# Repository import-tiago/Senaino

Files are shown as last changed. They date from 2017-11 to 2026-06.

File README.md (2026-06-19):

# Senaino




Senaino is an educational microcontroller board inspired by the Arduino UNO and adapted for technical training at SENAI. It was designed to help students practice soldering, electronics, bootloader recording and embedded programming with components that are easy to source in Brazil.

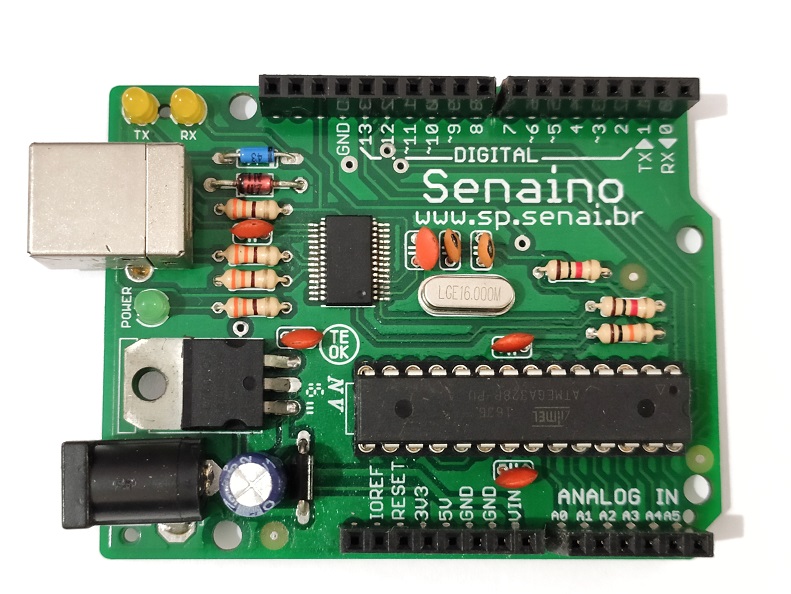
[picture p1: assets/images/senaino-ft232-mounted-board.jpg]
Senaino FT232 assembled board


## Overview

The goal was not only to make an Arduino-compatible board, but to create a reproducible hardware kit that could be fabricated, assembled and tested by students in a classroom or lab environment.

The work included schematic design, PCB layout, component selection, production files, assembly references, documentation and validation of the mounted board.

## Highlights

- Arduino UNO-inspired board based on the ATmega328P-PU.
- Two documented USB-to-serial variants: FT232RL and CH340G.
- Through-hole component strategy for beginner-friendly soldering practice.
- 16 MHz ATmega328P clock and Arduino-style headers.
- Open hardware files for Eagle, Gerber fabrication, schematic export and BOM.
- Dedicated assembly, testing, driver and bootloader documentation.

## Repository Map

```text
assets/
  images/          Project photos and workshop/gallery images.
  reference/       Board overlays and visual references for assembly.

docs/
  ft232/           FT232 assembly, BOM, production and testing notes.
  ch340/           CH340 assembly, BOM, production and testing notes.
  citation.md
  design-decisions.md
  drivers.md
  licensing.md
  variants.md

hardware/
  bom/             Spreadsheet and CSV bill of materials.
  eagle/           Eagle schematic and board files by variant.
  exports/         Schematic image/PDF exports.
  gerbers/         Fabrication files by variant.
```

## Documentation

- [Bootloader notes](docs/bootloader.md)
- [Citation and DOI guide](docs/citation.md)
- [Design decisions](docs/design-decisions.md)
- [Driver notes](docs/drivers.md)
- [License notes](docs/licensing.md)
- [Board variants](docs/variants.md)

| Variant | Assembly | Board overlay | BOM | Production | Testing |
|---|---|---|---|---|---|
| FT232 | [Guide](docs/ft232/assembly-guide.md) | [Overlay](assets/reference/senaino-ft232-components-silkscreen.png) | [BOM](docs/ft232/bill-of-materials.md) | [Files](docs/ft232/production.md) | [Checklist](docs/ft232/testing.md) |
| CH340 | [Guide](docs/ch340/assembly-guide.md) | [Overlay](assets/reference/senaino-ch340-components-silkscreen.png) | [BOM](docs/ch340/bill-of-materials.md) | [Files](docs/ch340/production.md) | [Checklist](docs/ch340/testing.md) |

## Hardware Files

| Variant | Eagle files | Schematic PDF | Gerbers | BOM |
|---|---|---|---|---|
| FT232 | [hardware/eagle/ft232-v1.0](hardware/eagle/ft232-v1.0) | [PDF](hardware/exports/senaino-ft232-schematic.pdf) | [Gerbers](hardware/gerbers/ft232-v1.0) | [CSV](hardware/bom/senaino-ft232-bom.csv) |
| CH340 | [hardware/eagle/ch340-v1.0](hardware/eagle/ch340-v1.0) | [PDF](hardware/exports/senaino-ch340-schematic.pdf) | [Gerbers](hardware/gerbers/ch340-v1.0) | [CSV](hardware/bom/senaino-ch340-bom.csv) |

## Board Variants

The repository documents two board variants in the `main` branch.

| Variant | USB-serial IC | Main advantage | Recommended use |
|---|---|---|---|
| FT232 | FT232RL | Traditional and widely documented | Original classroom version |
| CH340 | CH340G | Lower cost and avoids FT232 sourcing risk | Cost-sensitive or supply-risk-aware production |

The CH340 alternative exists because FT232RL sourcing can be risky. ZeptoBars documented real and fake FT232RL dies and described counterfeit/compatible chips that could behave differently with FTDI drivers: [FTDI FT232RL: real vs fake](https://zeptobars.com/en/read/FTDI-FT232RL-real-vs-fake-supereal).

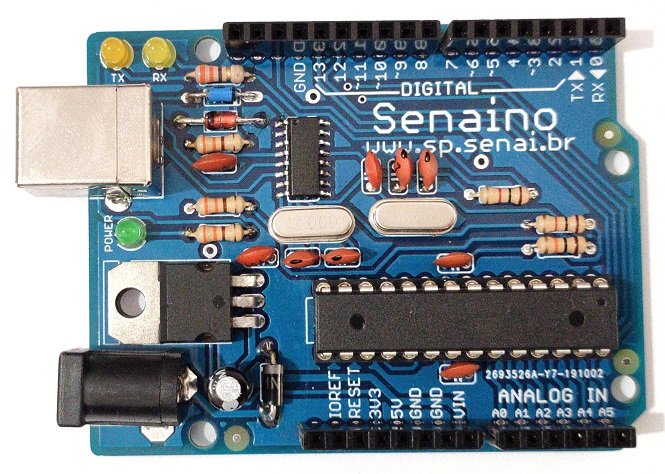
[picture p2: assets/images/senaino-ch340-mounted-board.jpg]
Senaino CH340 assembled board


## Gallery

| | | |
|---|---|---|
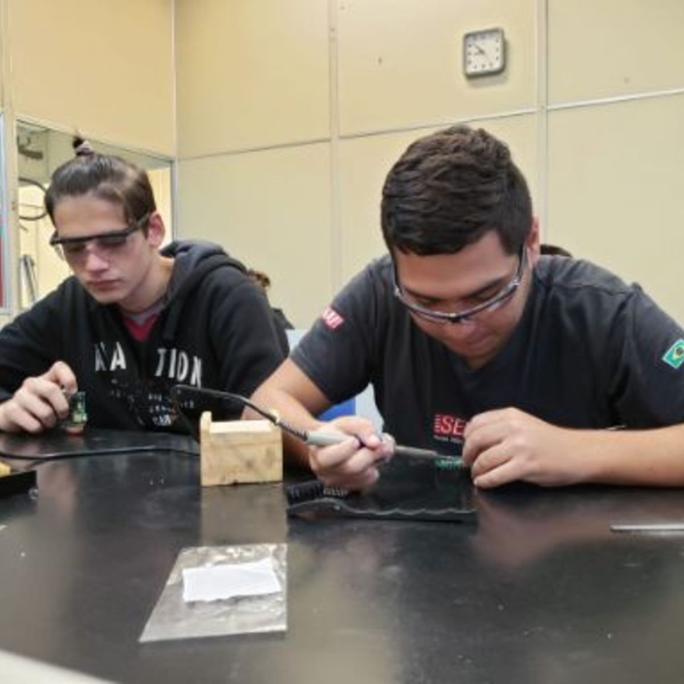
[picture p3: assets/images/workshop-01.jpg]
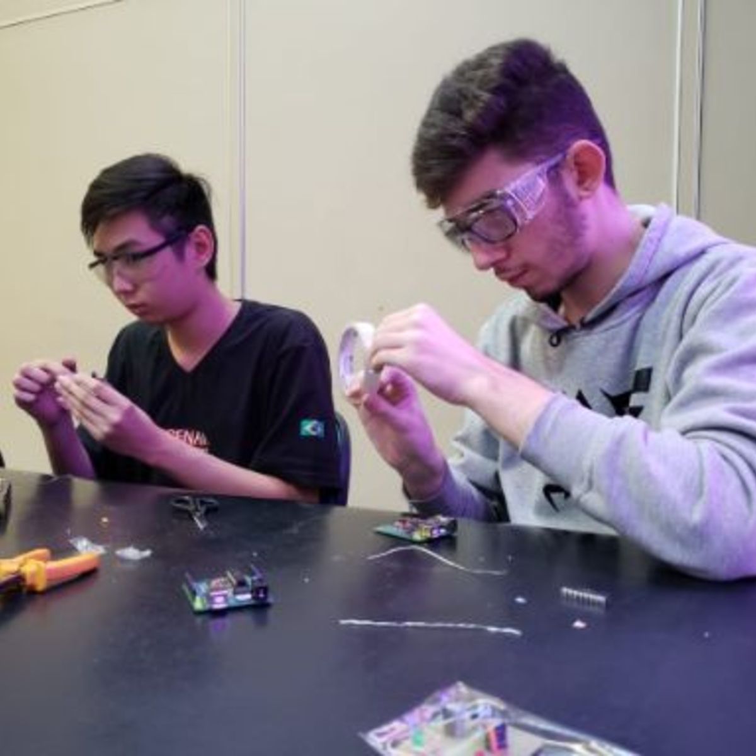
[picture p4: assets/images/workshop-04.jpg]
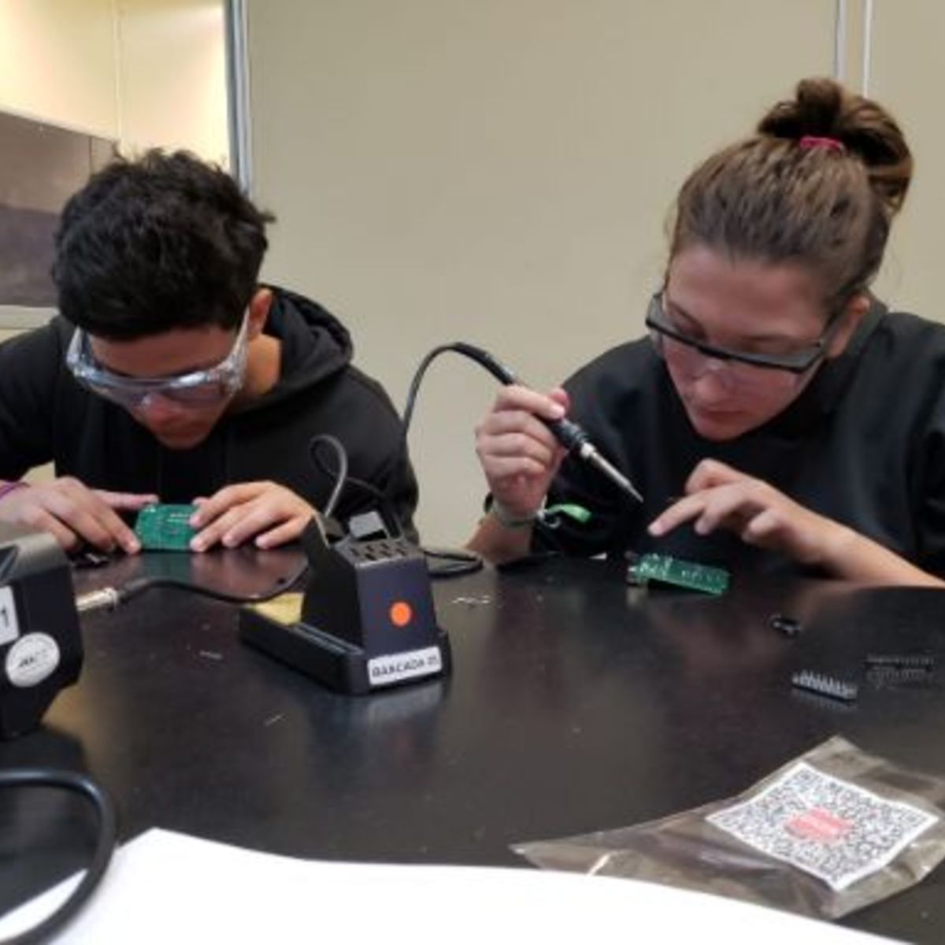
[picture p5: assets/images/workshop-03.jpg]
|  |  |  |
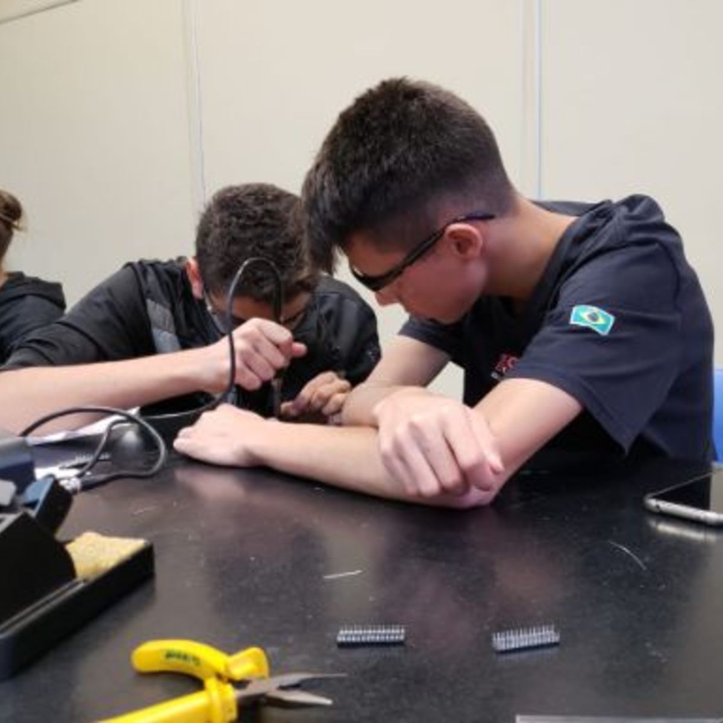
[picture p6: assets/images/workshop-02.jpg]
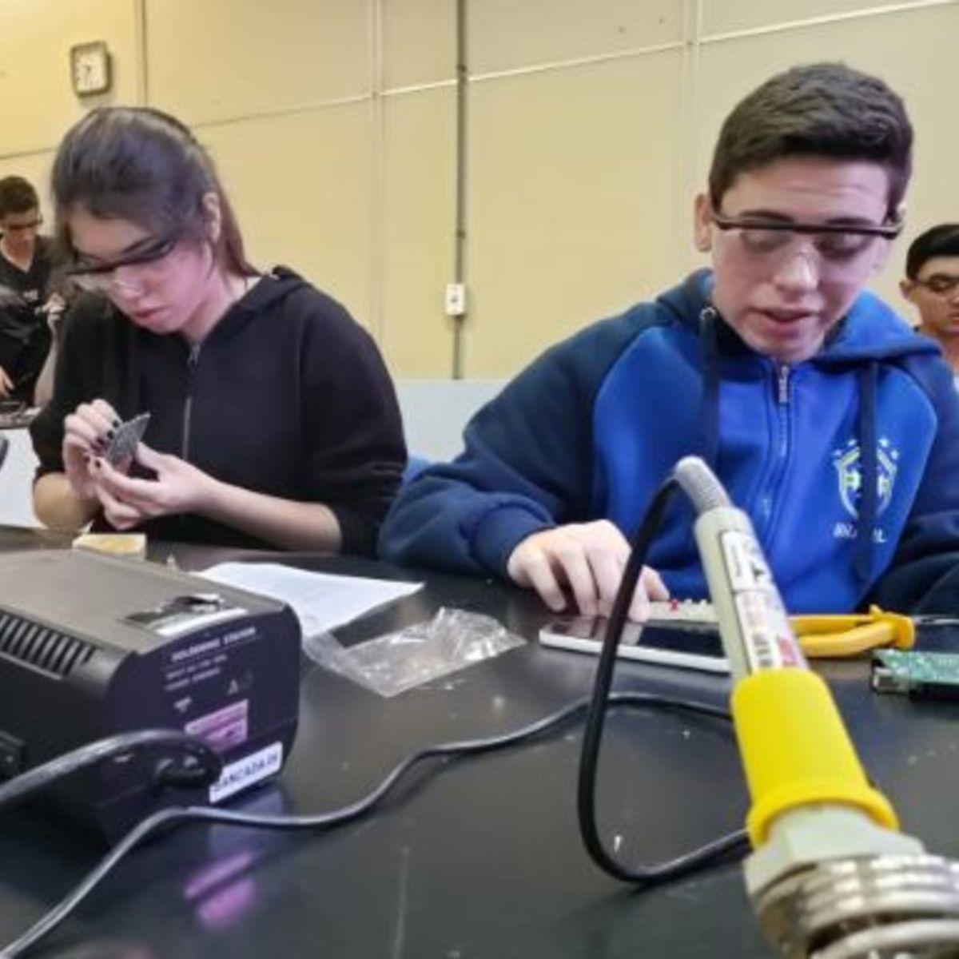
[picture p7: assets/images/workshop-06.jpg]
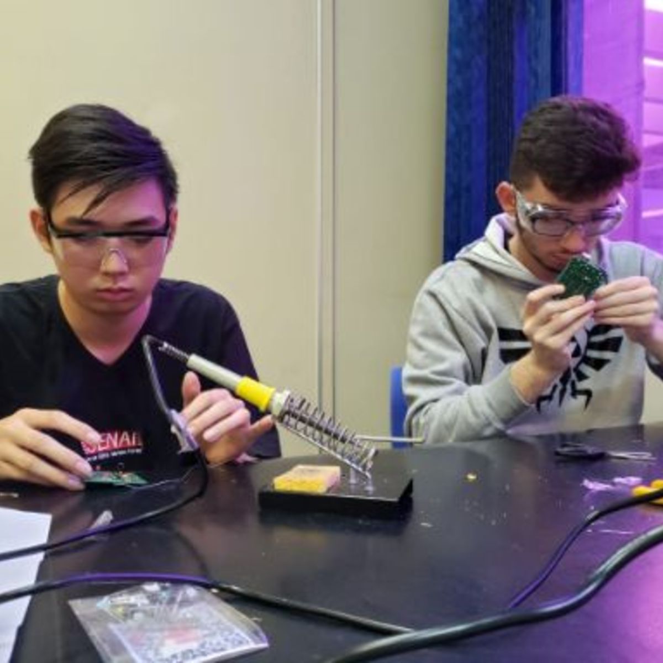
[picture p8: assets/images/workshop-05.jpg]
|  |  |  |
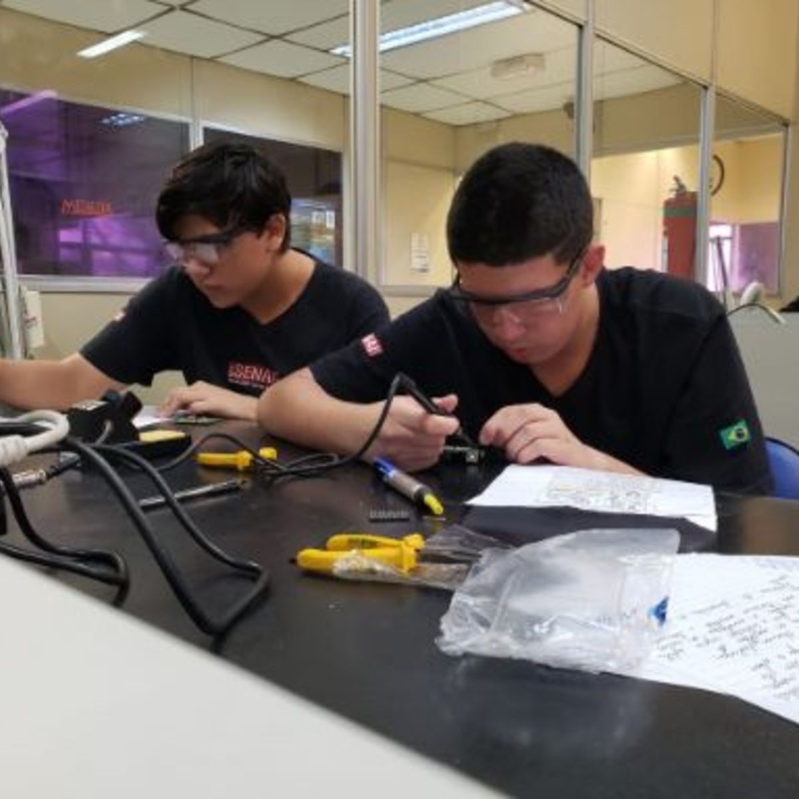
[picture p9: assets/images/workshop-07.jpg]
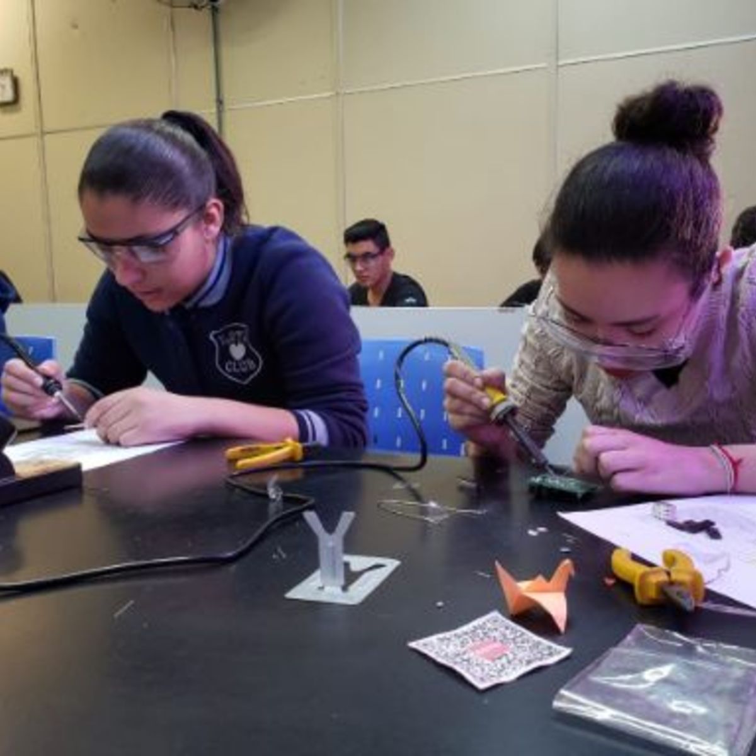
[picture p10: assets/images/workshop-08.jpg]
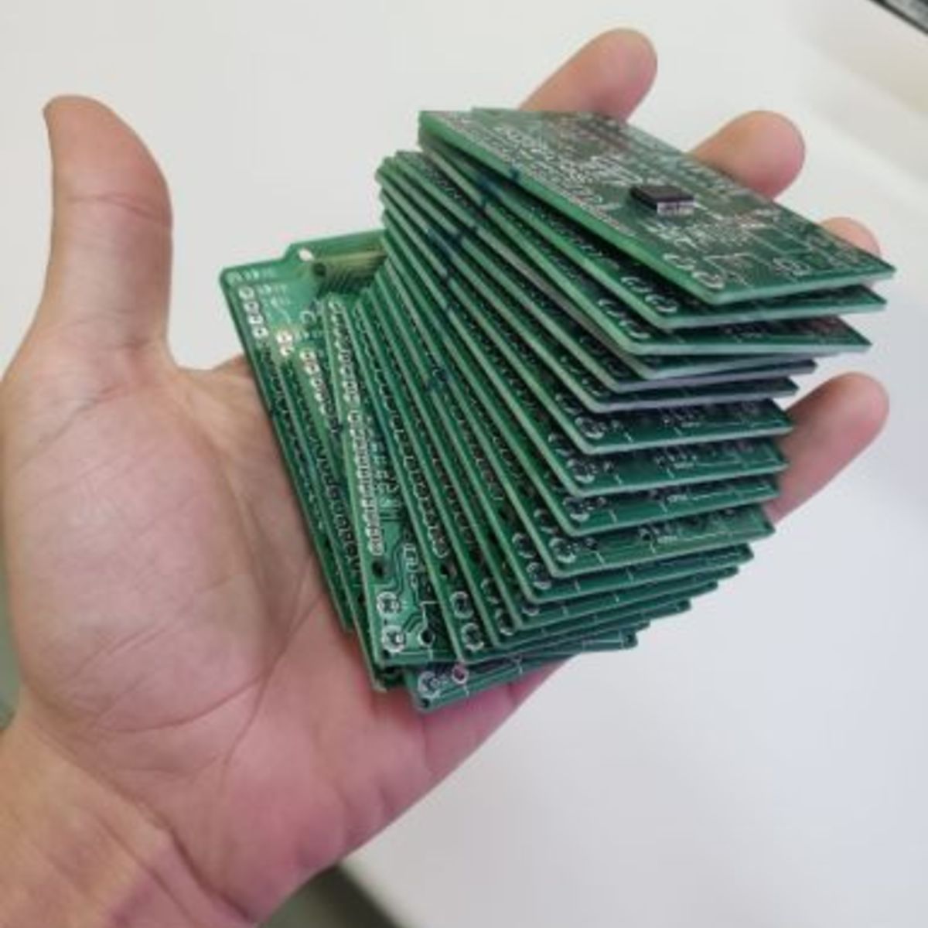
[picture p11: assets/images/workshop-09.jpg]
|  |  |  |

## Credits

Senaino was designed by Tiago Silva for educational use with [SENAI](https://www.sp.senai.br/) students. The board is inspired by the Arduino UNO reference design and keeps the educational spirit of open hardware.

## Citation

Citation metadata is available in [CITATION.cff](CITATION.cff).

## Contributing

See [CONTRIBUTING.md](CONTRIBUTING.md).

## License

The hardware design files are licensed under CERN-OHL-S-2.0. Documentation, images and educational material are licensed under CC BY-SA 4.0. See [LICENSE](LICENSE) and [docs/licensing.md](docs/licensing.md).

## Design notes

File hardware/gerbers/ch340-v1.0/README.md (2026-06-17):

# Senaino CH340 v1.0 Gerbers

This folder contains the fabrication files for the Senaino CH340 v1.0 board.

## Contents

| Path | Purpose |
|---|---|
| `CAMOutputs/GerberFiles/copper_top.gbr` | Top copper layer |
| `CAMOutputs/GerberFiles/copper_bottom.gbr` | Bottom copper layer |
| `CAMOutputs/GerberFiles/soldermask_top.gbr` | Top solder mask |
| `CAMOutputs/GerberFiles/soldermask_bottom.gbr` | Bottom solder mask |
| `CAMOutputs/GerberFiles/silkscreen_top.gbr` | Top silkscreen |
| `CAMOutputs/GerberFiles/silkscreen_bottom.gbr` | Bottom silkscreen |
| `CAMOutputs/GerberFiles/profile.gbr` | Board outline/profile |
| `CAMOutputs/DrillFiles/drill_1_16.xln` | Drill file |
| `CAMOutputs/Assembly/Senaino.txt` | Assembly export |

`senaino-ch340-v1.0-gerbers.zip` is the fabrication package generated from these open files.

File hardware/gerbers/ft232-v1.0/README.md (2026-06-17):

# Senaino FT232 v1.0 Gerbers

This folder contains the open fabrication files for the Senaino FT232 v1.0 board.

## Contents

| File | Purpose |
|---|---|
| `Senaino.top` | Top copper layer |
| `Senaino.bot` | Bottom copper layer |
| `Senaino.smt` | Top solder mask |
| `Senaino.smb` | Bottom solder mask |
| `Senaino.skt` | Top silkscreen |
| `Senaino.skb` | Bottom silkscreen |
| `Senaino.drd` | Drill data |
| `Senaino.dri` | Drill report/info |
| `Senaino.drl` | Drill rack/settings |
| `Senaino.gpi` | Gerber photoplotter information |

`senaino-ft232-v1.0-gerbers.zip` is the fabrication package generated from these open files.

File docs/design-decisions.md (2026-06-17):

# Design Decisions

Senaino was designed as an educational board, so the engineering choices prioritize teaching value, repairability, local sourcing and reproducibility.

## Arduino UNO-Inspired Format

The board follows the familiar Arduino UNO learning model because students can move from soldering and electrical testing to embedded programming without changing ecosystems.

## ATmega328P-PU

The ATmega328P-PU was selected because it is widely documented, classroom friendly and available in a DIP package. The removable DIP package also makes the board easier to inspect, replace and teach.

## Through-Hole Components

Most components are through-hole because the project is intended for soldering practice. This improves visibility during instruction and makes errors easier to diagnose.

## USB-Serial Variants

The FT232RL version prioritizes a traditional and well-documented USB-to-serial interface.

The CH340G version exists as a lower-cost and supply-risk-aware alternative. This matters because FT232RL sourcing can include counterfeit or protocol-compatible parts; ZeptoBars documented real and fake FT232RL dies and described driver-related behavior differences in counterfeit chips: [FTDI FT232RL: real vs fake](https://zeptobars.com/en/read/FTDI-FT232RL-real-vs-fake-supereal).

## Separate Production And Teaching Artifacts

The repository keeps Eagle sources, Gerber files, schematic exports, BOM data and assembly references separated by variant so that each audience can find what they need:

- Students use assembly and testing documents.
- Instructors use BOM and troubleshooting notes.
- Fabricators use Gerbers and production notes.
- Reviewers and researchers use the README, release notes and citation metadata.

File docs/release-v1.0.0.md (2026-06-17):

# Senaino v1.0.0 Release Notes

## Summary

This release archives Senaino as a consolidated open hardware project with FT232RL and CH340G USB-to-serial variants. The board is an educational Arduino UNO-inspired design for soldering, electronics and embedded programming training.

## Included Materials

- Eagle schematic and board files for FT232 and CH340 variants.
- Open Gerber fabrication files for both variants.
- ZIP fabrication packages.
- Schematic PDF and image exports.
- Board overlays/component placement references for both variants.
- Bills of materials in XLSX and CSV formats.
- Assembly guides.
- Testing checklists.
- Driver and bootloader notes.
- Citation metadata for DOI-based release.
- License overview for hardware and documentation assets.

## Variants

| Field | FT232 | CH340 |
|---|---|---|
| USB-serial IC | FT232RL | CH340G |
| Microcontroller | ATmega328P-PU | ATmega328P-PU |
| Main clock | 16 MHz | 16 MHz |
| USB-serial clock | Integrated/FT232RL | 12 MHz |

## Assembly Overlays

These overlays show where each component should be soldered on the PCB:

- FT232 board overlay: [assets/reference/senaino-ft232-components-silkscreen.png](https://github.com/import-tiago/Senaino/blob/main/assets/reference/senaino-ft232-components-silkscreen.png)
- CH340 board overlay: [assets/reference/senaino-ch340-components-silkscreen.png](https://github.com/import-tiago/Senaino/blob/main/assets/reference/senaino-ch340-components-silkscreen.png)

## Citation

After Zenodo archives this GitHub release, cite the release-specific DOI generated by Zenodo.

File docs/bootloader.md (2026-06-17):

# Bootloader Notes

Senaino uses an ATmega328P-PU with a 16 MHz crystal in both variants, so it can be programmed using the same general workflow used for Arduino UNO-compatible boards.

## Typical Workflow

1. Insert the ATmega328P-PU after power checks are complete.
2. Connect an ISP programmer to the board.
3. Select an Arduino UNO-compatible target.
4. Burn the bootloader.
5. Disconnect the ISP programmer.
6. Connect the board through USB.
7. Upload a simple Blink sketch.

## Educational Flow

For classroom use, the bootloader step is a good opportunity to teach:

- The difference between firmware, bootloader and sketch.
- Why the ATmega328P needs a clock source.
- How reset, serial upload and ISP programming relate to each other.
- How a blank microcontroller becomes Arduino-compatible.

## Related Project

For a specialized bootloader-burning workflow, see [GimmeSoul](https://github.com/import-tiago/GimmeSoul).

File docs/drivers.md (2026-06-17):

# Driver Notes

Do not store driver installers in the repository. Download USB-serial drivers from the official vendor pages when needed.

## FT232 Variant

The FT232 variant uses the FT232RL USB-to-serial converter.

- Official FTDI VCP drivers: https://ftdichip.com/drivers/vcp-drivers/
- On many modern Linux distributions, FTDI VCP support is already available through the kernel.
- On Windows, install the official VCP driver only when the board is not detected automatically.

## CH340 Variant

The CH340 variant uses the CH340G USB-to-serial converter.

- Official WCH CH341/CH340 driver page: https://www.wch-ic.com/downloads/CH341SER_EXE.html

## Repository Policy

Binary installers such as `.exe` files are intentionally not versioned here. Keeping drivers as external links avoids stale binaries, reduces repository size and makes the hardware documentation easier to audit.

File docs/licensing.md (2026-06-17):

# Licensing

Senaino is distributed as an open hardware project with separate licenses for hardware design material and educational/documentation material.

## Hardware License

The hardware design sources and manufacturing files are licensed under the CERN Open Hardware Licence Version 2 - Strongly Reciprocal.

SPDX identifier: `CERN-OHL-S-2.0`

This applies to:

- `hardware/eagle/`
- `hardware/gerbers/`
- `hardware/exports/`
- `hardware/bom/`

The CERN-OHL-S-2.0 license is a hardware-focused reciprocal license. It is more appropriate for PCB design files than using only a documentation/content license.

## Documentation And Media License

Documentation, images, repository text and educational material are licensed under Creative Commons Attribution-ShareAlike 4.0 International.

SPDX identifier: `CC-BY-SA-4.0`

This applies to:

- `README.md`
- `CHANGELOG.md`
- `CONTRIBUTING.md`
- `CITATION.cff`
- `.zenodo.json`
- `docs/`
- `assets/`

## Attribution

When reusing or modifying this project, attribute:

Tiago Silva, Senaino, https://github.com/import-tiago/Senaino

For academic or technical citation, prefer the DOI generated by the Zenodo release. See [citation.md](citation.md).

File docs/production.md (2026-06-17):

# Production Files

The FT232 fabrication files are in [../hardware/gerbers/ft232-v1.0](../hardware/gerbers/ft232-v1.0).

## Available Files

| File | Purpose |
|---|---|
| `Senaino.top` | Top copper layer |
| `Senaino.bot` | Bottom copper layer |
| `Senaino.smt` | Top solder mask |
| `Senaino.smb` | Bottom solder mask |
| `Senaino.skt` | Top silkscreen |
| `Senaino.skb` | Bottom silkscreen |
| `Senaino.drd` | Drill data |
| `Senaino.dri` | Drill report/info |
| `Senaino.drl` | Drill rack/settings |
| `Senaino.gpi` | Gerber photoplotter information |

## Packages

- Open files: [../hardware/gerbers/ft232-v1.0](../hardware/gerbers/ft232-v1.0)
- ZIP package: [../hardware/gerbers/ft232-v1.0/senaino-ft232-v1.0-gerbers.zip](../hardware/gerbers/ft232-v1.0/senaino-ft232-v1.0-gerbers.zip)

## Fabrication Notes

Before ordering boards, open the Gerbers in a viewer and confirm:

- Board outline.
- Layer alignment.
- Drill positions.
- USB connector footprint.
- Silkscreen readability.
- Solder mask clearance.

Typical low-cost fabrication settings for this type of board are 2 layers, 1.6 mm FR-4 and 1 oz copper, but confirm the final specification with the selected manufacturer before ordering.

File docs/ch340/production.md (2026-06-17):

# Production Files

The CH340 fabrication files are in [../../hardware/gerbers/ch340-v1.0](../../hardware/gerbers/ch340-v1.0).

## Available Files

| Path | Purpose |
|---|---|
| `CAMOutputs/GerberFiles/copper_top.gbr` | Top copper layer |
| `CAMOutputs/GerberFiles/copper_bottom.gbr` | Bottom copper layer |
| `CAMOutputs/GerberFiles/soldermask_top.gbr` | Top solder mask |
| `CAMOutputs/GerberFiles/soldermask_bottom.gbr` | Bottom solder mask |
| `CAMOutputs/GerberFiles/silkscreen_top.gbr` | Top silkscreen |
| `CAMOutputs/GerberFiles/silkscreen_bottom.gbr` | Bottom silkscreen |
| `CAMOutputs/GerberFiles/profile.gbr` | Board outline/profile |
| `CAMOutputs/DrillFiles/drill_1_16.xln` | Drill file |
| `CAMOutputs/Assembly/Senaino.txt` | Assembly export |
| `CAMOutputs/Assembly/PnP_Senaino_front.txt` | Front pick-and-place export |
| `CAMOutputs/Assembly/PnP_Senaino_back.txt` | Back pick-and-place export |

## Packages

- Open files: [../../hardware/gerbers/ch340-v1.0/CAMOutputs](../../hardware/gerbers/ch340-v1.0/CAMOutputs)
- ZIP package: [../../hardware/gerbers/ch340-v1.0/senaino-ch340-v1.0-gerbers.zip](../../hardware/gerbers/ch340-v1.0/senaino-ch340-v1.0-gerbers.zip)

## Fabrication Notes

Before ordering boards, open the Gerbers in a viewer and confirm:

- Board outline.
- Layer alignment.
- Drill positions.
- USB connector footprint.
- Silkscreen readability.
- Solder mask clearance.

Typical low-cost fabrication settings for this type of board are 2 layers, 1.6 mm FR-4 and 1 oz copper, but confirm the final specification with the selected manufacturer before ordering.

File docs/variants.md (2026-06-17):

# Board Variants

Senaino has two documented USB-to-serial variants in the `main` branch.

| Variant | USB-serial IC | Notes |
|---|---|---|
| FT232 | FT232RL | Original classroom version. |
| CH340 | CH340G | Lower-cost alternative kept in the same repository. |

## FT232 Version

The FT232 version is useful when the priority is a traditional USB-to-serial interface with broad documentation and known behavior.

## CH340 Version

The CH340 version is useful when production cost, local availability and USB-to-serial sourcing risk matter more than keeping the original FT232RL interface.

It also reduces the sourcing risk around FT232RL parts. ZeptoBars documented a real-vs-fake comparison of FT232RL dies and described counterfeit/protocol-compatible parts that behaved differently with FTDI driver updates: [FTDI FT232RL: real vs fake](https://zeptobars.com/en/read/FTDI-FT232RL-real-vs-fake-supereal).

## Choosing A Variant

| Situation | Recommended variant |
|---|---|
| Reference documentation and traditional FTDI workflow | FT232 |
| Classroom production with lower cost target | CH340 |
| Debugging with known FTDI tooling | FT232 |
| Bulk manufacturing where CH340 is easier to source or FT232 authenticity is uncertain | CH340 |

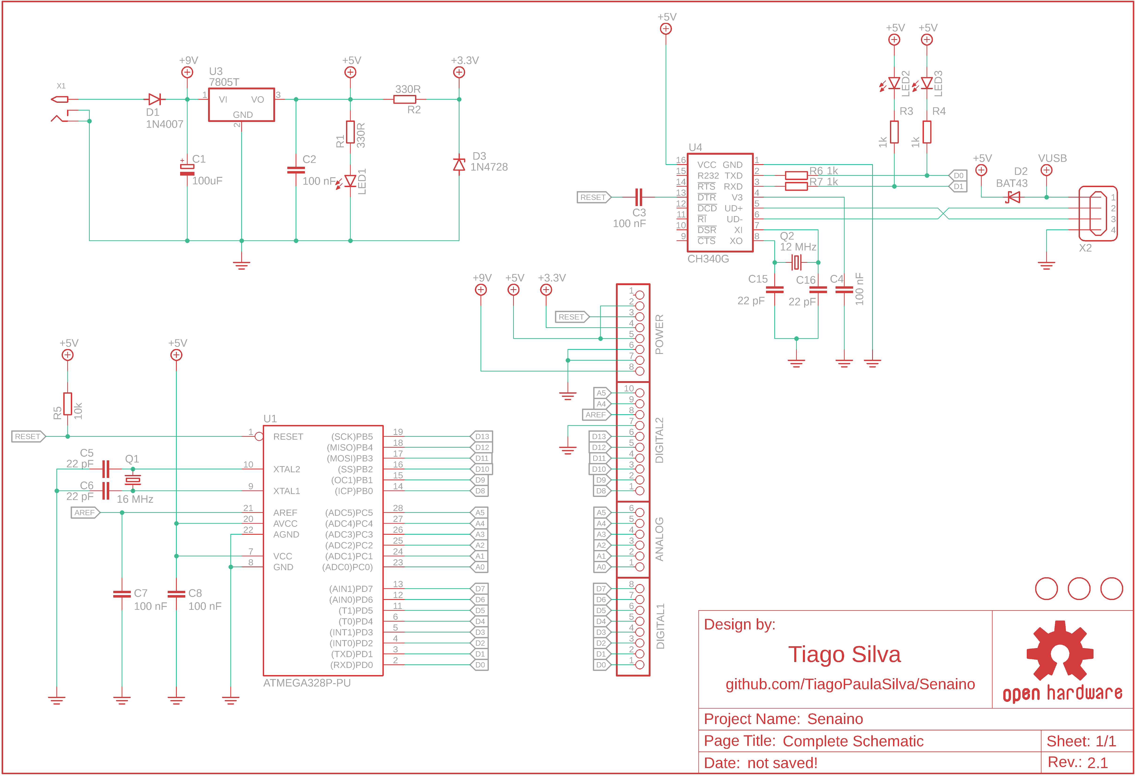
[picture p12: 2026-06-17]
hardware/exports/senaino-ch340-schematic.png

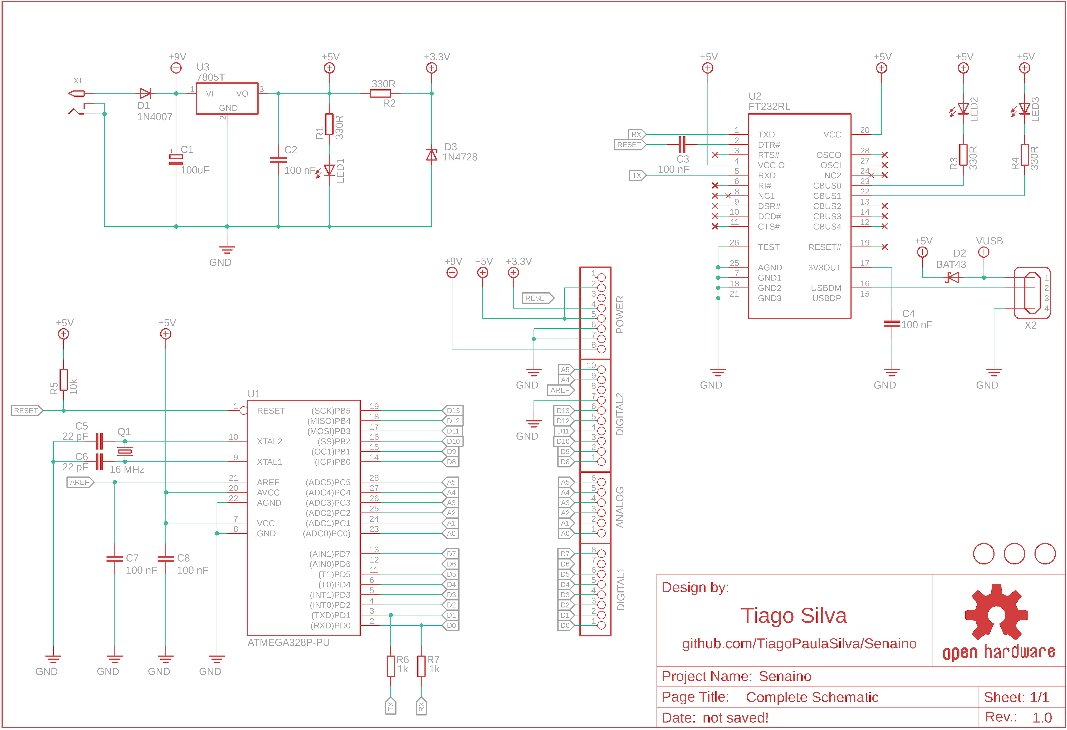
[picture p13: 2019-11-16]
hardware/exports/senaino-ft232-schematic.png

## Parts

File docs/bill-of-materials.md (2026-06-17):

# Bill Of Materials

This is the human-readable BOM for the Senaino FT232 version. The spreadsheet version is available at [../hardware/bom/senaino-ft232-bom.xlsx](../hardware/bom/senaino-ft232-bom.xlsx), and the CSV version is available at [../hardware/bom/senaino-ft232-bom.csv](../hardware/bom/senaino-ft232-bom.csv).

| Qty | Parts | Description | Value | Package |
|---:|---|---|---|---|
| 1 | R2 | PTH resistor | 150 ohm +/-5% | CR25 1/4 W |
| 3 | R1/R3/R4 | PTH resistor | 330 ohm +/-5% | CR25 1/4 W |
| 2 | R6/R7 | PTH resistor | 1 kohm +/-5% | CR25 1/4 W |
| 1 | R5 | PTH resistor | 10 kohm +/-5% | CR25 1/4 W |
| 5 | C2/C3/C4/C7/C8 | PTH ceramic capacitor | 100 nF x 50 V | Disc |
| 2 | C5/C6 | PTH ceramic capacitor | 22 pF x 50 V | Disc |
| 1 | C1 | PTH electrolytic capacitor | 100 uF x 35 V | Radial |
| 1 | D1 | PTH rectifier diode | 1N4007 | DO-41 |
| 1 | D2 | PTH Schottky diode | BAT43 | DO-35 |
| 1 | D3 | PTH Zener diode | 1N4728 | DO-41 |
| 1 | LED1 | PTH LED | Green | 3 mm |
| 2 | LED2/LED3 | PTH LED | Yellow | 3 mm |
| 1 | Q1 | PTH crystal | 16 MHz | HC49/S |
| 1 | U1 | PTH microcontroller | ATmega328P-PU | DIP-28N |
| 1 | U1 | PTH IC socket | 28 pins | DIP-28N |
| 1 | U2 | SMD USB/serial converter | FT232RL | SSOP-28 |
| 1 | U3 | PTH voltage regulator | L7805CV | TO-220 |
| 1 | X1 | PTH power connector | Jack J4, 2.1 mm | 3 terminals |
| 1 | X2 | PTH USB connector | Female USB Type-B | PCB 90 degrees |
| 1 | - | PTH pin header | Female 180 degrees | 1x10 |
| 2 | - | PTH pin header | Female 180 degrees | 1x8 |
| 1 | - | PTH pin header | Female 180 degrees | 1x6 |

## Sourcing Notes

- Prefer through-hole components for the student assembly workflow.
- Keep extra resistors, LEDs and ceramic capacitors available during classes.
- Treat the FT232RL, ATmega328P-PU and USB connector as critical components.
- Confirm the USB-to-serial IC package before ordering replacement parts.

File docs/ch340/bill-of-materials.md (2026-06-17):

# Bill Of Materials

This is the human-readable BOM for the Senaino CH340 version. The spreadsheet version is available at [../../hardware/bom/senaino-ch340-bom.xlsx](../../hardware/bom/senaino-ch340-bom.xlsx), and the CSV version is available at [../../hardware/bom/senaino-ch340-bom.csv](../../hardware/bom/senaino-ch340-bom.csv).

| Qty | Parts | Description | Value | Package |
|---:|---|---|---|---|
| 1 | R2 | PTH resistor | 150 ohm +/-5% | CR25 1/4 W |
| 1 | R1 | PTH resistor | 330 ohm +/-5% | CR25 1/4 W |
| 4 | R3/R4/R6/R7 | PTH resistor | 1 kohm +/-5% | CR25 1/4 W |
| 1 | R5 | PTH resistor | 10 kohm +/-5% | CR25 1/4 W |
| 5 | C2/C3/C4/C7/C8 | PTH ceramic capacitor | 100 nF x 50 V | Disc |
| 4 | C5/C6/C15/C16 | PTH ceramic capacitor | 22 pF x 50 V | Disc |
| 1 | C1 | PTH electrolytic capacitor | 100 uF x 35 V | Radial |
| 1 | D1 | PTH rectifier diode | 1N4007 | DO-41 |
| 1 | D2 | PTH Schottky diode | BAT43 | DO-35 |
| 1 | D3 | PTH Zener diode | 1N4728 | DO-41 |
| 1 | LED1 | PTH LED | Green | 3 mm |
| 2 | LED2/LED3 | PTH LED | Yellow | 3 mm |
| 1 | Q1 | PTH crystal | 16 MHz | HC49/S |
| 1 | Q2 | PTH crystal | 12 MHz | HC49/S |
| 1 | U1 | PTH microcontroller | ATmega328P-PU | DIP-28N |
| 1 | U1 | PTH IC socket | 28 pins | DIP-28N |
| 1 | U4 | SMD USB/serial converter | CH340G | SOP-16 |
| 1 | U3 | PTH voltage regulator | L7805CV | TO-220 |
| 1 | X1 | PTH power connector | Jack J4, 2.1 mm | 3 terminals |
| 1 | X2 | PTH USB connector | Female USB Type-B | PCB 90 degrees |
| 1 | - | PTH pin header | Female 180 degrees | 1x10 |
| 2 | - | PTH pin header | Female 180 degrees | 1x8 |
| 1 | - | PTH pin header | Female 180 degrees | 1x6 |

## Sourcing Notes

- Prefer through-hole components for the student assembly workflow.
- Keep extra resistors, LEDs and ceramic capacitors available during classes.
- Treat the CH340G, ATmega328P-PU, crystals and USB connector as critical components.
- Confirm the USB-to-serial IC package before ordering replacement parts.

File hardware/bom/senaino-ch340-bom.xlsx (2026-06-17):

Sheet: MONTAGEM
Designator | Description
C1 | Capacitor Eletrolítico - 100 uF x 35 V
C2 | Capacitor Disco Cerâmico - 100 nF x 50 V
C3 | Capacitor Disco Cerâmico - 100 nF x 50 V
C4 | Capacitor Disco Cerâmico - 100 nF x 50 V
C7 | Capacitor Disco Cerâmico - 100 nF x 50 V
C8 | Capacitor Disco Cerâmico - 100 nF x 50 V
C5 | Capacitor Disco Cerâmico - 22 pF x 50 V
C6 | Capacitor Disco Cerâmico - 22 pF x 50 V
C15 | Capacitor Disco Cerâmico - 22 pF x 50 V
C16 | Capacitor Disco Cerâmico - 22 pF x 50 V
D1 | Diodo Retificador - 1N4007
D2 | Diodo Schottky - BAT43
D3 | Diodo Zener - 1N4728
LED1 | LED Difuso 3 mm - Verde
LED2 | LED Difuso 3 mm - Amarelo
LED3 | LED Difuso 3 mm - Amarelo
Q1 | Cristal 16 MHz - HC49S
Q2 | Cristal 12 MHz - HC49S
R1 | Resistor 330 Ω, 1/4 W - CR25
R2 | Resistor 150 Ω, 1/4 W - CR25
R3 | Resistor 1 kΩ, 1/4 W - CR25
R4 | Resistor 1 kΩ, 1/4 W - CR25
R5 | Resistor 10 kΩ, 1/4 W - CR25
R6 | Resistor 1 kΩ, 1/4 W - CR25
R7 | Resistor 1 kΩ, 1/4 W - CR25
U1 | Microcontrolador - ATMEGA328P-PU
U1 | Soquete Torneado Slim - 28 Pinos
U4 | Conversor USB/UART - CH340G
U3 | Regulador de Tensão Positivo - L7805CV
X1 | Conector Jack DC J4, 2.1 mm, 3 Terminais
X2 | Conector USB Tipo B, Fêmea, 90° PCI
- | Barra de Pinos 1x40 Vias, 180 Graus, Passo 2,54mm - Fêmea
- | Cabo USB 2.0 A/B, 1.8 metros

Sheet: COMPRA
Qtd./PCI | Descrição | Valor/unidade | Valor Toral
2 | Capacitor Eletrolítico - 100 uF x 35 V | R$0.25 | R$0.50
10 | Capacitor Disco Cerâmico - 100 nF x 50 V | R$0.10 | R$1.00
4 | Capacitor Disco Cerâmico - 22 pF x 50 V | R$0.10 | R$0.40
2 | Diodo Retificador - 1N4007 | R$0.25 | R$0.50
2 | Diodo Schottky - BAT43 | R$0.35 | R$0.70
2 | Diodo Zener - 1N4728 | R$0.40 | R$0.80
2 | LED Difuso 3 mm - Verde | R$0.35 | R$0.70
4 | LED Difuso 3 mm - Amarelo | R$0.35 | R$1.40
2 | Cristal 16 MHz - HC49S | R$1.00 | R$2.00
6 | Resistor 330 Ω, 1/4 W - CR25 | R$0.05 | R$0.30
2 | Resistor 150 Ω, 1/4 W - CR25 | R$0.05 | R$0.10
2 | Resistor 10 kΩ, 1/4 W - CR25 | R$0.05 | R$0.10
4 | Resistor 1 kΩ, 1/4 W - CR25 | R$0.05 | R$0.20
2 | Microcontrolador - ATMEGA328P-PU | R$27.00 | R$54.00
2 | Soquete Torneado Slim - 28 Pinos | R$1.80 | R$3.60
2 | Conversor USB/UART - FT232RL SMD | R$25.00 | R$50.00
2 | Regulador de Tensão Positivo - L7805CV | R$1.50 | R$3.00
2 | Conector Jack DC J4, 2.1 mm, 3 Terminais P/ PCI | R$1.90 | R$3.80
2 | Conector USB Tipo B, Fêmea, 90° PCI | R$2.30 | R$4.60
2 | Barra de Pinos 1x40 Vias, 180 Graus, Passo 2,54mm - Fêmea | R$0.80 | R$1.60
2 | Cabo USB A/B, 1.8 metros | R$10.00 | R$20.00
10 | PCI fibra de vidro dupla face 35 cm x 23 cm | R$15.00 | R$150.00
Valor Final |  |  | R$299.30

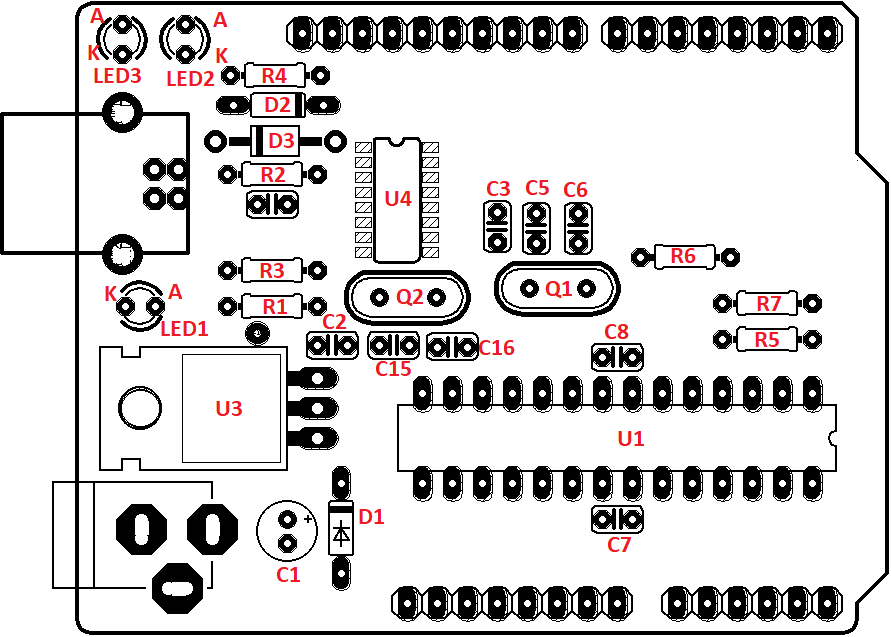
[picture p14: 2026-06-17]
assets/reference/senaino-ch340-components-silkscreen.png

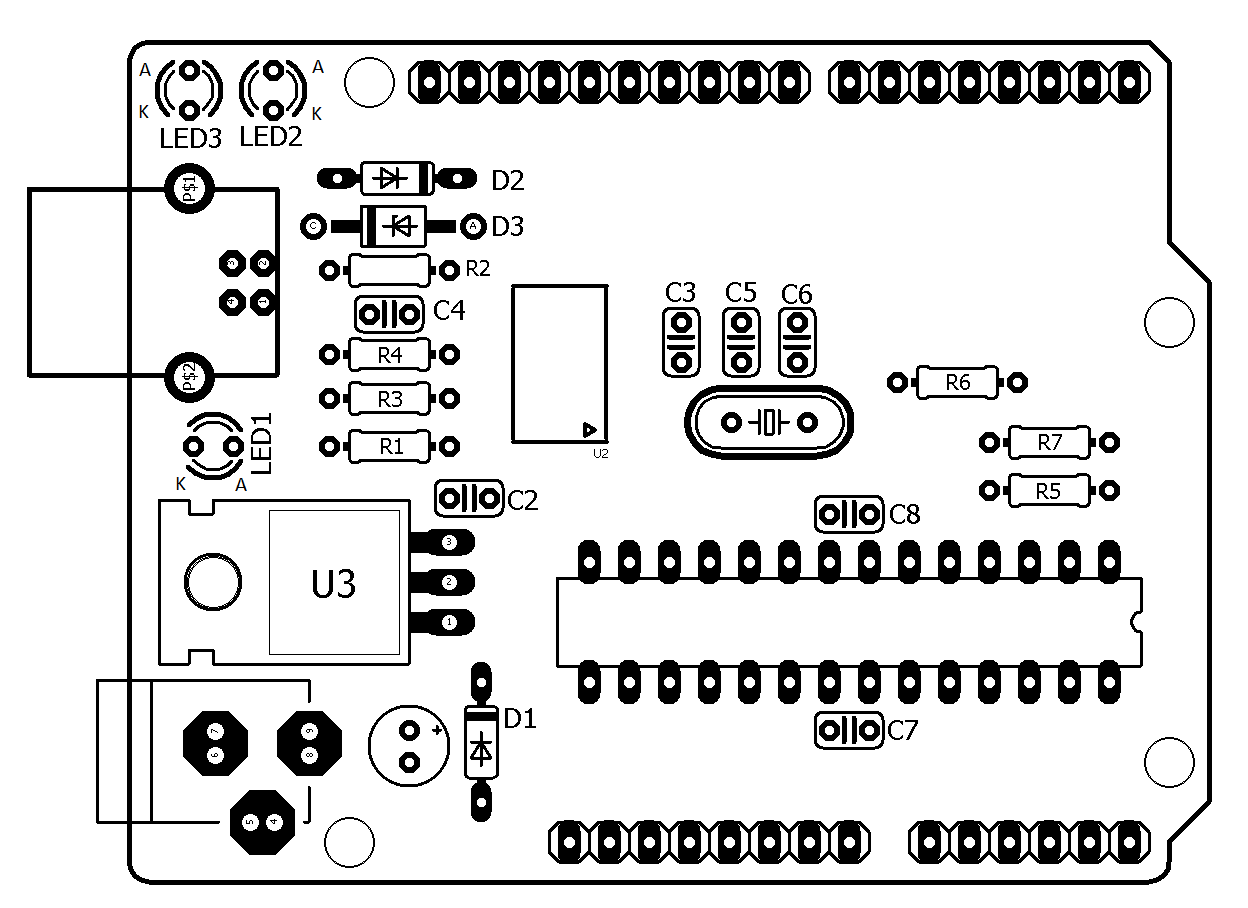
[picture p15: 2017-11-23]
assets/reference/senaino-ft232-components-silkscreen.png

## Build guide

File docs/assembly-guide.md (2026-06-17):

# Assembly Guide

This guide is intended for classroom assembly of the Senaino FT232 board.

## Reference Files

- Component placement reference: [../assets/reference/senaino-ft232-components-silkscreen.png](../assets/reference/senaino-ft232-components-silkscreen.png)
- Schematic PDF: [../hardware/exports/senaino-ft232-schematic.pdf](../hardware/exports/senaino-ft232-schematic.pdf)
- BOM: [bill-of-materials.md](bill-of-materials.md)

## Recommended Assembly Order

1. Inspect the PCB for scratches, broken traces or solder mask damage.
2. Solder the lowest-profile passive components first: resistors and small diodes.
3. Solder ceramic capacitors.
4. Solder the crystal.
5. Solder the IC socket for the ATmega328P-PU. Do not insert the microcontroller yet.
6. Solder LEDs, observing polarity.
7. Solder the electrolytic capacitor, observing polarity.
8. Solder the voltage regulator and power jack.
9. Solder pin headers.
10. Solder the USB connector.
11. Solder or inspect the FT232RL USB-to-serial IC.
12. Clean flux residue and visually inspect all joints.
13. Insert the ATmega328P-PU only after the power checks pass.

## Polarity Notes

| Part | What to check |
|---|---|
| D1, D2, D3 | Match the diode stripe with the board marking. |
| LED1, LED2, LED3 | Match anode/cathode orientation with the silkscreen. |
| C1 | Match the negative stripe on the capacitor with the negative pad. |
| U1 | Align pin 1/notch with the IC socket and board marking. |
| U3 | Confirm orientation before powering the board. |

## Soldering Notes

- Start with components that are mechanically easy to hold flat against the PCB.
- Keep solder joints shiny, conical and limited to the pad area.
- Avoid overheating the FT232RL and USB connector pads.
- Recheck for bridges around the FT232RL before connecting USB.
- Do not insert the ATmega328P-PU until the 5 V rail has been tested.

## Final Assembly Checklist

- No visible solder bridges.
- No loose component leads.
- USB connector mechanically firm.
- Power jack mechanically firm.
- Headers aligned vertically.
- ATmega328P-PU inserted with correct orientation.
- Board passes the electrical tests in [testing.md](testing.md).

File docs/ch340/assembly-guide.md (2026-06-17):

# Assembly Guide

This guide is intended for classroom assembly of the Senaino CH340 board.

## Reference Files

- Board overlay/component placement reference: [../../assets/reference/senaino-ch340-components-silkscreen.png](../../assets/reference/senaino-ch340-components-silkscreen.png)
- Schematic PDF: [../../hardware/exports/senaino-ch340-schematic.pdf](../../hardware/exports/senaino-ch340-schematic.pdf)
- BOM: [bill-of-materials.md](bill-of-materials.md)

## Recommended Assembly Order

1. Inspect the PCB for scratches, broken traces or solder mask damage.
2. Solder the lowest-profile passive components first: resistors and small diodes.
3. Solder ceramic capacitors.
4. Solder the 16 MHz and 12 MHz crystals.
5. Solder the IC socket for the ATmega328P-PU. Do not insert the microcontroller yet.
6. Solder LEDs, observing polarity.
7. Solder the electrolytic capacitor, observing polarity.
8. Solder the voltage regulator and power jack.
9. Solder pin headers.
10. Solder the USB connector.
11. Solder or inspect the CH340G USB-to-serial IC.
12. Clean flux residue and visually inspect all joints.
13. Insert the ATmega328P-PU only after the power checks pass.

## Polarity Notes

| Part | What to check |
|---|---|
| D1, D2, D3 | Match the diode stripe with the board marking. |
| LED1, LED2, LED3 | Match anode/cathode orientation with the silkscreen. |
| C1 | Match the negative stripe on the capacitor with the negative pad. |
| U1 | Align pin 1/notch with the IC socket and board marking. |
| U3 | Confirm orientation before powering the board. |

## Soldering Notes

- Start with components that are mechanically easy to hold flat against the PCB.
- Keep solder joints shiny, conical and limited to the pad area.
- Avoid overheating the CH340G and USB connector pads.
- Recheck for bridges around the CH340G before connecting USB.
- Do not insert the ATmega328P-PU until the 5 V rail has been tested.

## Final Assembly Checklist

- No visible solder bridges.
- No loose component leads.
- USB connector mechanically firm.
- Power jack mechanically firm.
- Headers aligned vertically.
- ATmega328P-PU inserted with correct orientation.
- Board passes the electrical tests in [testing.md](testing.md).

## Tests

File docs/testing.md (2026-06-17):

# Testing Checklist

Use this checklist before giving a mounted board to a student or using it in class.

## Before Power

1. Inspect the board under good light.
2. Check continuity between GND points.
3. Confirm there is no short between 5 V and GND.
4. Confirm there is no short between VIN and GND.
5. Confirm diode and electrolytic capacitor orientation.
6. Confirm the ATmega328P-PU is not inserted for the first power test.

## Power Rail Test

1. Power the board from the DC jack or USB, according to the test setup.
2. Measure the regulated 5 V rail.
3. Confirm the power LED behavior.
4. Disconnect power immediately if the regulator overheats.
5. Insert the ATmega328P-PU only after the power rail is correct.

## USB-Serial Test

1. Connect the board through USB.
2. Confirm that the operating system detects a serial port.
3. If the serial port does not appear, check [drivers.md](drivers.md).
4. Open the serial port with the Arduino IDE or another serial terminal.
5. Confirm that reset and upload behavior are stable.

## Bootloader And Blink Test

1. Burn the bootloader using the notes in [bootloader.md](bootloader.md).
2. Select the Arduino UNO-compatible target in the programming environment.
3. Upload a Blink sketch.
4. Confirm the expected LED behavior.
5. Repeat USB reconnection to confirm the board enumerates consistently.

## Acceptance Criteria

- 5 V rail is stable.
- No short is detected after power cycling.
- USB serial port enumerates.
- Bootloader can be recorded.
- Blink sketch uploads successfully.
- Board resets correctly during upload.

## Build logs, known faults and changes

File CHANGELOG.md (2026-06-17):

# Changelog

## Unreleased

- Consolidated FT232 and CH340 into the `main` branch.
- Preserved CH340 hardware files, documentation, BOM, schematic exports and Gerbers in variant-specific folders.
- Added FT232 sourcing-risk context and CH340 justification with a ZeptoBars reference.
- Updated citation metadata for a single consolidated DOI release.
- Reorganized the repository for portfolio presentation.
- Added dedicated documentation for assembly, testing, drivers, bootloader, variants and production.
- Added design decision and contribution notes.
- Added a Markdown and CSV bill of materials.
- Moved hardware source files into `hardware/`.
- Moved images and visual references into `assets/`.
- Extracted the FT232 Gerber files and added a ZIP fabrication package.
- Removed the bundled driver executable from version control.

## FT232 v1.0.0

- Prepared the FT232 variant for citation and DOI-based release.
- Added `CITATION.cff` and Zenodo metadata.
- Clarified licensing for hardware design files and documentation assets.

## FT232 v1.0

- Initial documented FT232 board version.

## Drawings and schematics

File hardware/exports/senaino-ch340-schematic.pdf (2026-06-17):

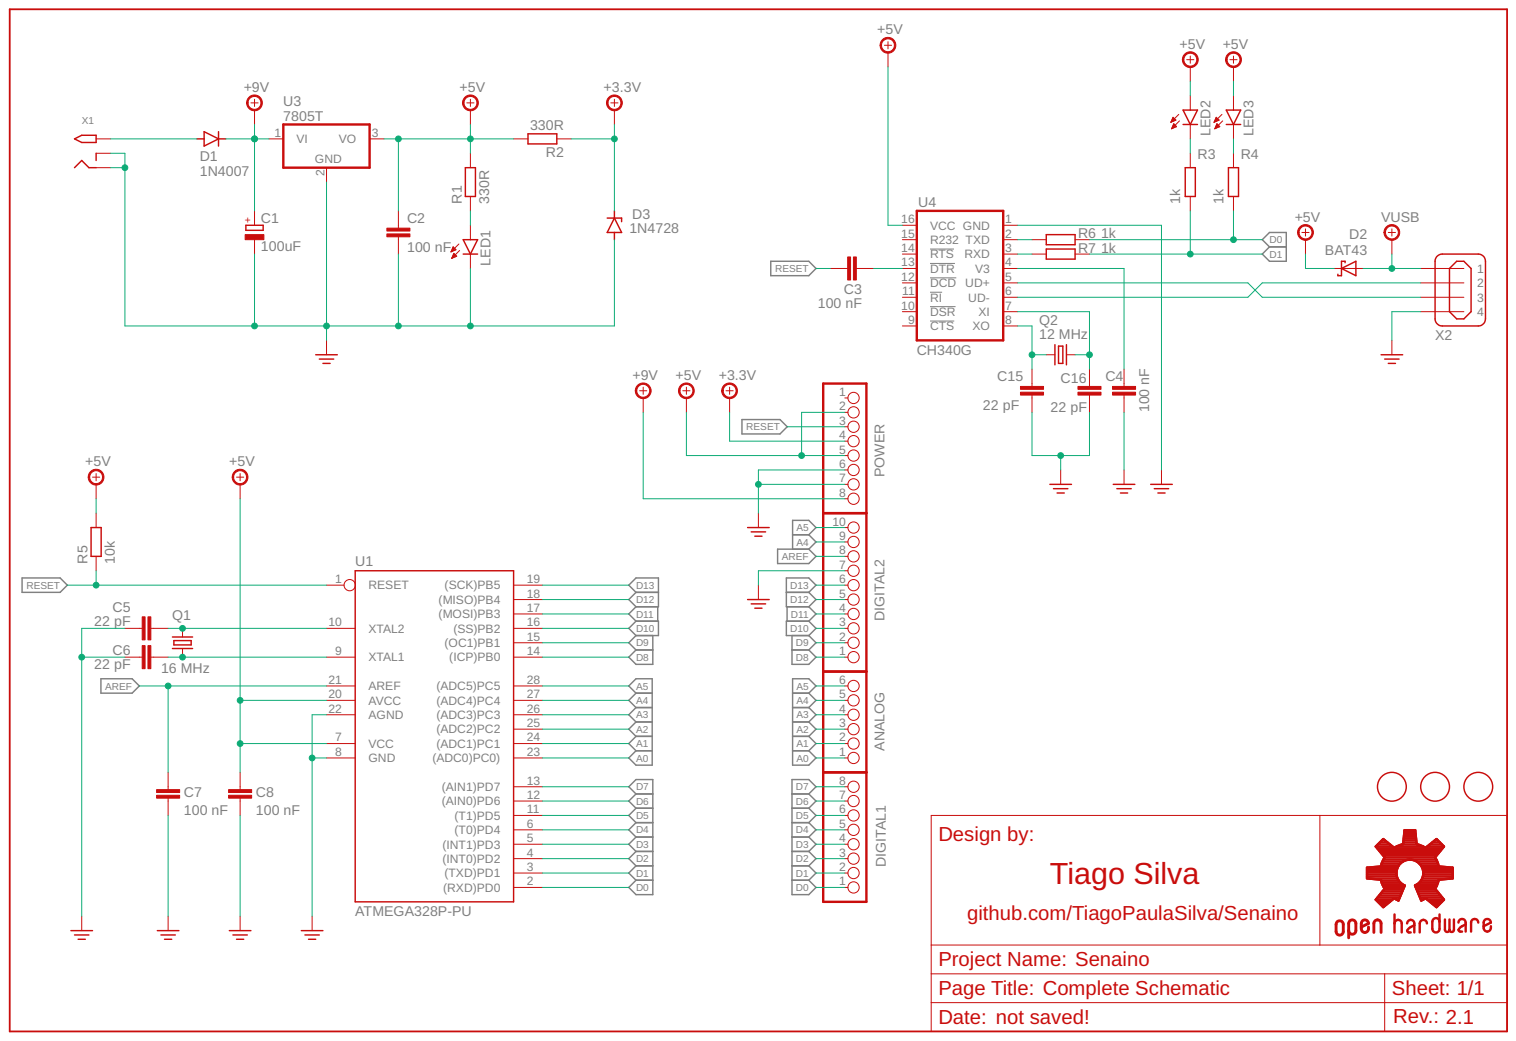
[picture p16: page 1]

github.com/TiagoPaulaSilva/Senaino

Page Title: Complete Schematic | Sheet: 1/1
Date: not saved! | Rev.: 2.1

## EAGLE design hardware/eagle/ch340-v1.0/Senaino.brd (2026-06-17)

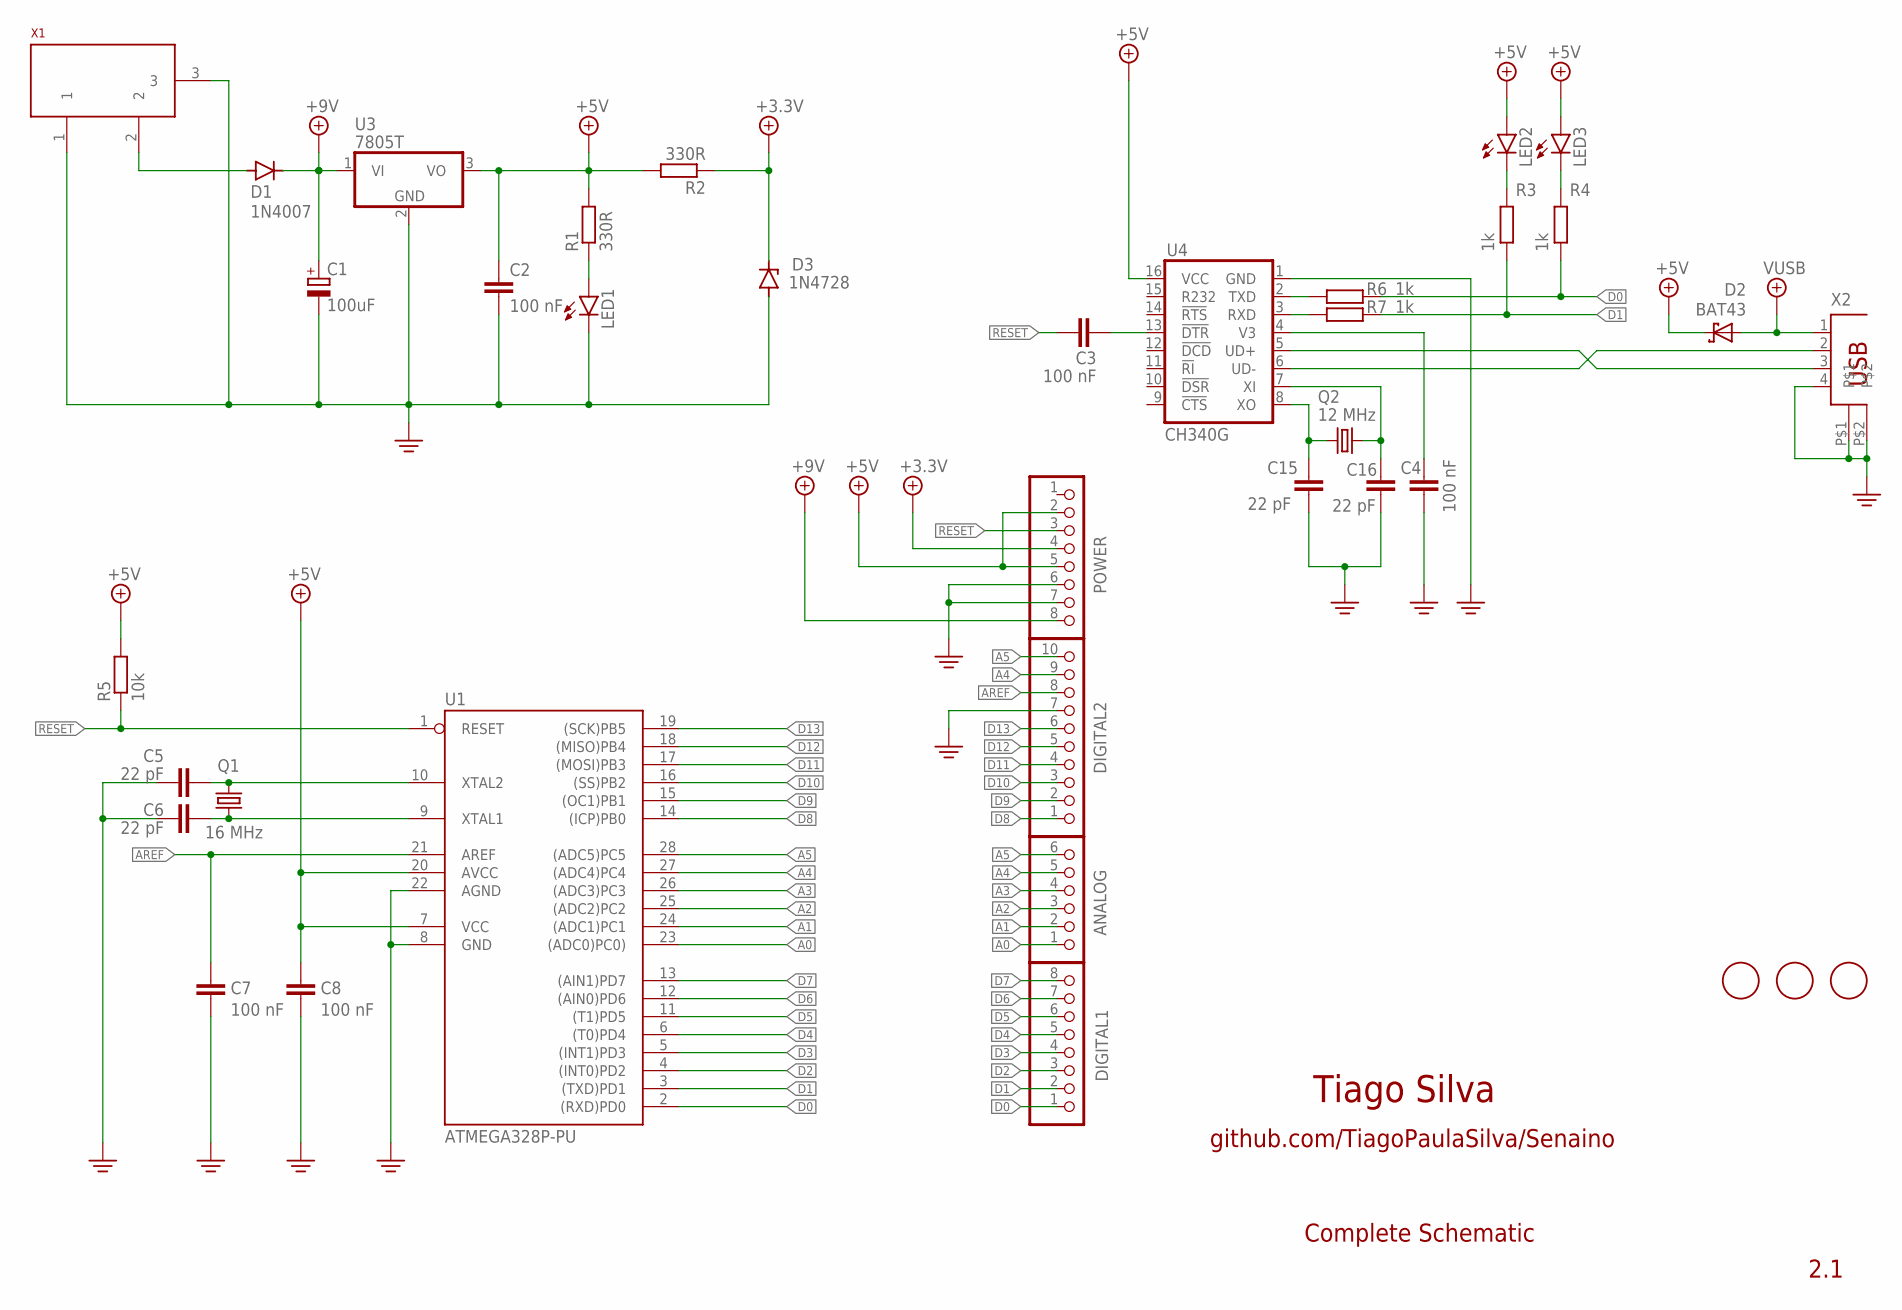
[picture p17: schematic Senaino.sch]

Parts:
ANALOG: PINHD-1X6; 1X06
C1: 100uF; E2-5
C2, C3, C4, C7, C8: 100 nF; C025-024X044
C5, C6, C15, C16: 22 pF; C025-024X044
D1: 1N4007; DO35-7
D2: BAT43; DIODE_DO35-7
D3: 1N4728; DO41Z10
DIGITAL1: PINHD-1X8; 1X08
DIGITAL2: PINHD-1X10_ARD; 1X10
FD1, FD2, FD3: FIDUCIALMOUNT; FIDUCIA-MOUNT
LED1, LED2, LED3: LED3MM
POWER: PINHD-1X8; 1X08
Q1: 16 MHz; HC49/S
Q2: 12 MHz; HC49/S
R1, R2: 330R; 0204/7
R3, R4, R6, R7: 1k; 0204/7
R5: 10k; 0204/7
U1: ATMEGA328P-PU; DIL28-3
U3: 7805T; TO220H
U4: CH340G; SO016
X1: POWERSUPPLY_DC21MMX; POWERSUPPLY_DC-21MM
X2: PN61729

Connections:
+3.3V: D3.C, POWER.4, R2.1
+5V: C2.1, C8.1, D2.C (A), LED2.A, LED3.A, POWER.2, POWER.5, R1.2, R2.2, R5.2, U1.7 (VCC), U1.20 (AVCC), U3.3 (VO), U4.16 (VCC)
+9V: C1.+, D1.C, POWER.8, U3.1 (VI)
A0: ANALOG.1, U1.23 ((ADC0)PC0))
A1: ANALOG.2, U1.24 ((ADC1)PC1)
A2: ANALOG.3, U1.25 ((ADC2)PC2)
A3: ANALOG.4, U1.26 ((ADC3)PC3)
A4: ANALOG.5, DIGITAL2.9, U1.27 ((ADC4)PC4)
A5: ANALOG.6, DIGITAL2.10, U1.28 ((ADC5)PC5)
AREF: C7.1, DIGITAL2.8, U1.21 (AREF)
D0: DIGITAL1.1, R4.1, R6.2, U1.2 ((RXD)PD0)
D1: DIGITAL1.2, R3.1, R7.2, U1.3 ((TXD)PD1)
D2: DIGITAL1.3, U1.4 ((INT0)PD2)
D3: DIGITAL1.4, U1.5 ((INT1)PD3)
D4: DIGITAL1.5, U1.6 ((T0)PD4)
D5: DIGITAL1.6, U1.11 ((T1)PD5)
D6: DIGITAL1.7, U1.12 ((AIN0)PD6)
D7: DIGITAL1.8, U1.13 ((AIN1)PD7)
D8: DIGITAL2.1, U1.14 ((ICP)PB0)
D9: DIGITAL2.2, U1.15 ((OC1)PB1)
D10: DIGITAL2.3, U1.16 ((SS)PB2)
D11: DIGITAL2.4, U1.17 ((MOSI)PB3)
D12: DIGITAL2.5, U1.18 ((MISO)PB4)
D13: DIGITAL2.6, U1.19 ((SCK)PB5)
GND: C1.-, C2.2, C4.1, C5.1, C6.1, C7.2, C8.2, C15.1, C16.1, D3.A, DIGITAL2.7, LED1.K (C), POWER.6, POWER.7, U1.8 (GND), U1.22 (AGND), U3.2 (GND), U4.1 (GND), X1.1, X1.3, X2.4, X2.P$1, X2.P$2
unnamed: D1.A, X1.2
unnamed: U4.5 (UD+), X2.3
unnamed: C3.2, U4.13 (!DTR)
unnamed: R6.1, U4.2 (TXD)
unnamed: U4.6 (UD-), X2.2
unnamed: LED2.K (C), R3.2
unnamed: LED3.K (C), R4.2
unnamed: R7.1, U4.3 (RXD)
unnamed: C4.2, U4.4 (V3)
unnamed: C15.2, Q2.2, U4.8 (XO)
unnamed: C16.2, Q2.1, U4.7 (XI)
unnamed: C5.2, Q1.2, U1.10 (XTAL2)
unnamed: C6.2, Q1.1, U1.9 (XTAL1)
unnamed: LED1.A, R1.1
RESET: C3.1, POWER.3, R5.1, U1.1 (RESET)
VUSB: D2.A (C), X2.1

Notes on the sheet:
Tiago Silva
github.com/TiagoPaulaSilva/Senaino
2.1
Complete Schematic

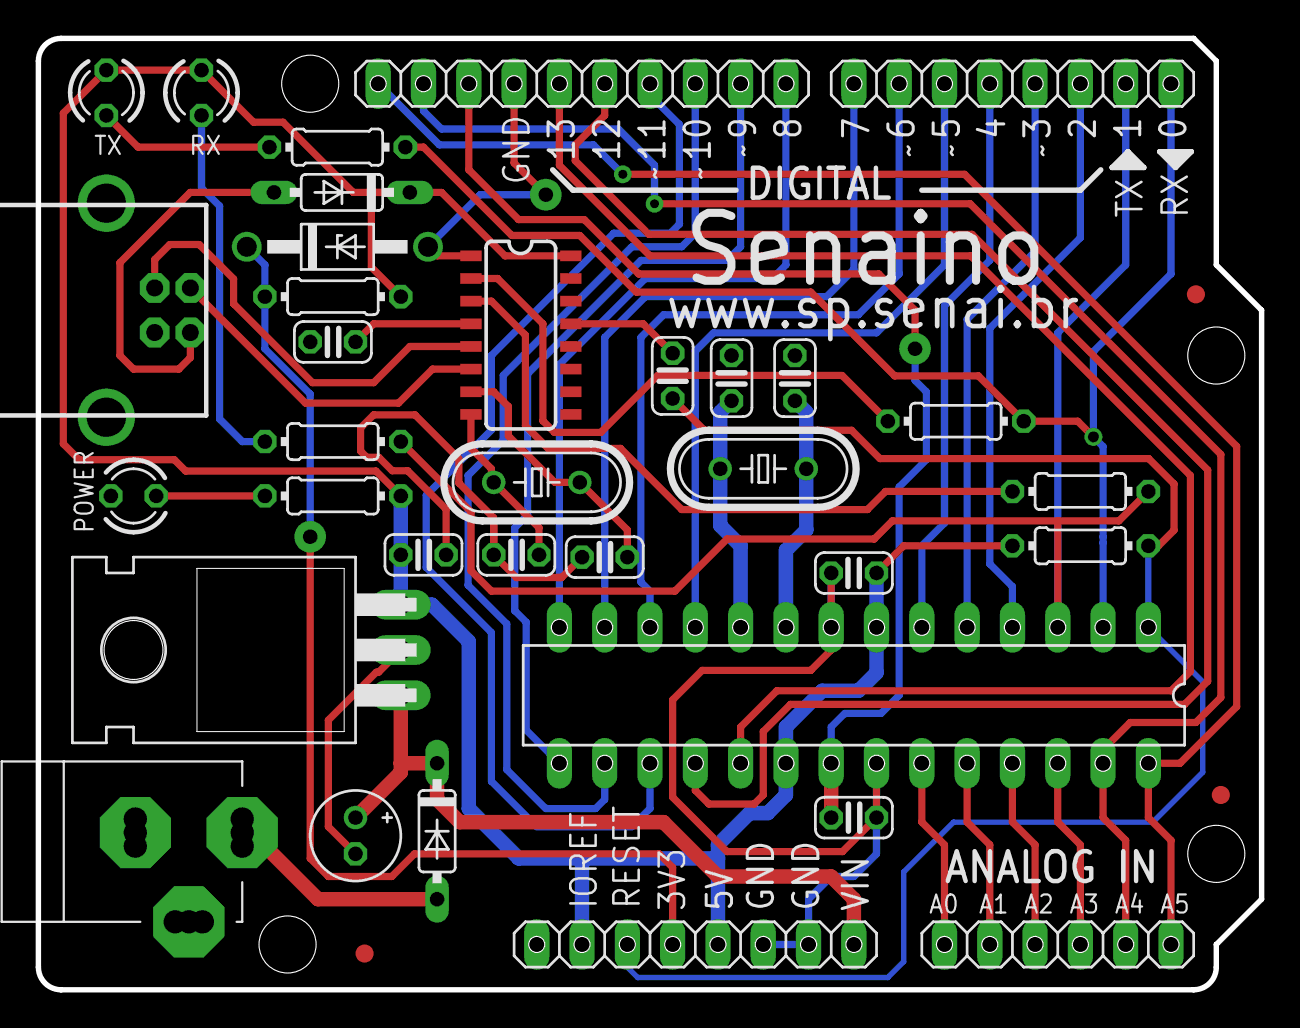
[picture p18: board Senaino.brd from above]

Board: 2 copper layers, 68.6 x 53.3 mm, 37 parts (0 on the bottom side), 41 nets.

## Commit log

2017-04-27 Add files via upload
    100% functional design.
    [Catraquino.sch, Senaino.brd, Senaino.sch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]
2017-06-21 Update README.md
    Inserting Illustrative Image
2017-08-28 Add files via upload
    bill of materials
    [Bill of Materials.xlsx]
2018-07-18 FTDI Driver Upoload
2018-07-18 Update README.md
    Recommended FTDI Driver
2019-06-19 Files organized by folders
    - Nothing has changed in the project.
    - Only improved the organization of the files.
    [Bill of Materials.xlsx, Senaino.brd, Senaino.sch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]
2019-07-22 Frame schematic updated
    [Senaino.brd, Senaino.sch]
2019-11-09 Mounted Board Photo updated
2019-11-16 Add schematic as a image
2019-11-18 All files added to a .rar file
    [Senaino.drl]
2026-06-17 Reorganize repository for portfolio presentation
    [Senaino.brd, Senaino.sch, senaino-ft232-bom.csv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]
2026-06-17 Consolidate CH340 variant into main
    [Senaino.brd, Senaino.sch, senaino-ch340-bom.csv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]
2026-06-17 Document board overlays for release

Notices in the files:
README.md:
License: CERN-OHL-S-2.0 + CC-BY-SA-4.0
